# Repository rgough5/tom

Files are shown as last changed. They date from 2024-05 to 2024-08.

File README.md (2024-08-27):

# TOM Observes Mice (single pi)
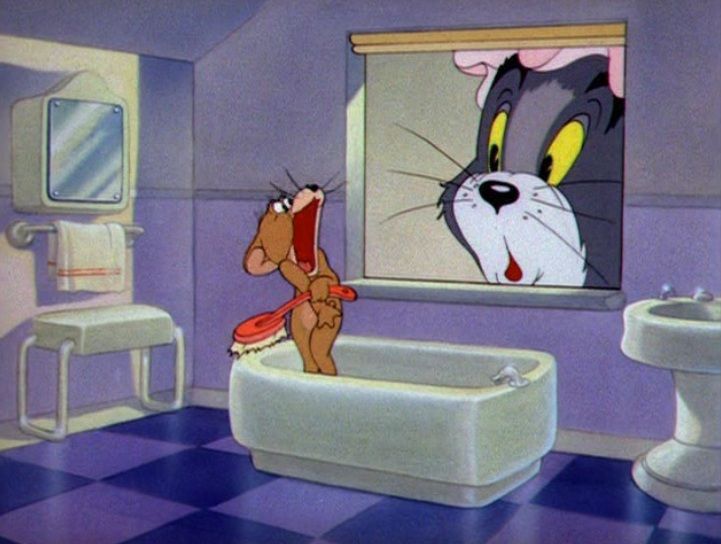
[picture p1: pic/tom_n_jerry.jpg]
this is fair use right?


While stable and functional, TOM is still a bit clunky so please report an issues. Note that it may be difficult to run further processes on the RasPi while recording and would only recommend live video analysis if you modify the AV data to be streamed as opposed to locally saved.

TOM Observes Mice (TOM) is a simple and relatively cheap tool for scientists interested in peeping on mice in their natural habit. Their home cage.
With a second raspberry pi, you can also record ultrasonic audio that will be syncronized with video.
Once setup, this tool is simple to use and written in Python so that other researchers can modify it as necessary.

## Required Hardware
- raspberry pi 5
- 5V/5A power adapter
- [solid state drive](https://www.amazon.com/SAMSUNG-Technology-Intelligent-Turbowrite-Sequential/dp/B08V7GT6F3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) and an [SSD hat](https://www.amazon.com/GeeekPi-N07-Peripheral-Raspberry-Support/dp/B0CWD266XR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)
    - note that gen4 SSDs are not compaitble with current SSD mounts. The highest you can go is gen3
    - with default settings you should be able to record for a minimum of a month before the SSD is full.
- raspberry pi camera [with IR filter removed](https://www.raspberrypi.com/documentation/accessories/camera.html#filter-removal)
- camera lens
    - tested with arducam 120 degree wide angle lens
- Dodotronic ultramic UM250K microphone
    - Requires separate USB A-to-mini-B cable

## Recommended Hardware
- Some sort of case. .dxf file include in the repository can be used to cut a frame out of 2.75mm acrylic, but this frame is flimsy and provides little protection. The pi(s) and camera are held in place using 12 m2.5 screws and nuts with the laser cut washers acting as spacers.
- Cooling. While heatsinks were sufficient in testing, I recommend active cooling with a fan.
- A router and potentially network switches to setup a LAN for communication between pis and a long term storage.

## Build
Instructions with pictures to come when more general casing is designed.

### Installation
1. Install Raspberry Pi OS (lite recommended) onto your SSD with custom settings. In the custom settings select username, a unique hostname, setup wifi, and **most importantly** enable SSH.
    - Be sure to enter a hostname unique to other devices on network.
2. Before progressing, the pi will need to be on and [connected to the internet](https://www.raspberrypi.com/documentation/computers/configuration.html#networking).
3. It's good practice on first boot to run `sudo apt-get update` and `sudo apt-get upgrade`
4. enter `curl -O https://raw.githubusercontent.com/rgough5/tom/main/install_tom.sh` to download the installer
5. Run the install file `bash install_tom.sh`.
6. *Optional:* Currently, files are transfered to another computer over ssh. You will need to setup passwordless connections if you want to use this.

### Usage
1. **If** you would like to run the raspi headless *(recommendeded)*.
    1. Connect the controlling computer to the same network as the pi.
    2. Connect to the raspi with `ssh -XC user@ip`.
2. **If** you would like to automatically setup
2. Run the python script with `python recAV.py`
    1. You will prompted to enter the file prefix, recording length, whether to record audio, and whether to transfer files after recordings

### Issues
- Adjusting settings is difficult and typically results in worse image.
- When recording with audio, video quality must be limitted to 10fps and 480p. Great for file size and good enough for most longitudinal use cases.

### In progress
- Working on GUI

Contact Rhys at rgough5@jhu.edu for any questions, requests, etc.

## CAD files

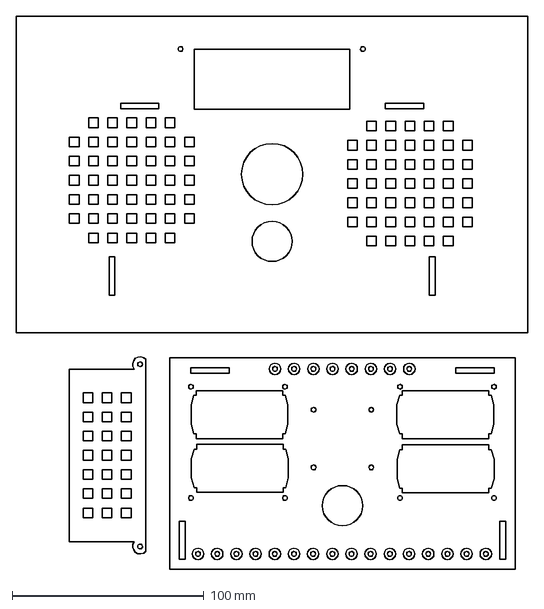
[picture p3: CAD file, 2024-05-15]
housing/cage_lid.DXF
266.7 x 288.3 mm

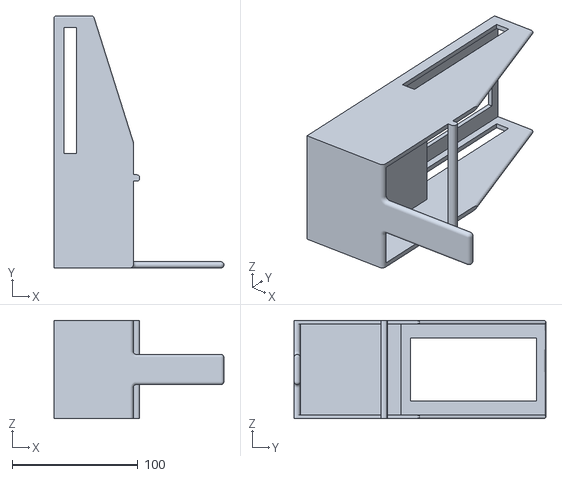
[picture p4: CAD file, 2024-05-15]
housing/bottleholder2.STL
135.0 x 200.0 x 78.0

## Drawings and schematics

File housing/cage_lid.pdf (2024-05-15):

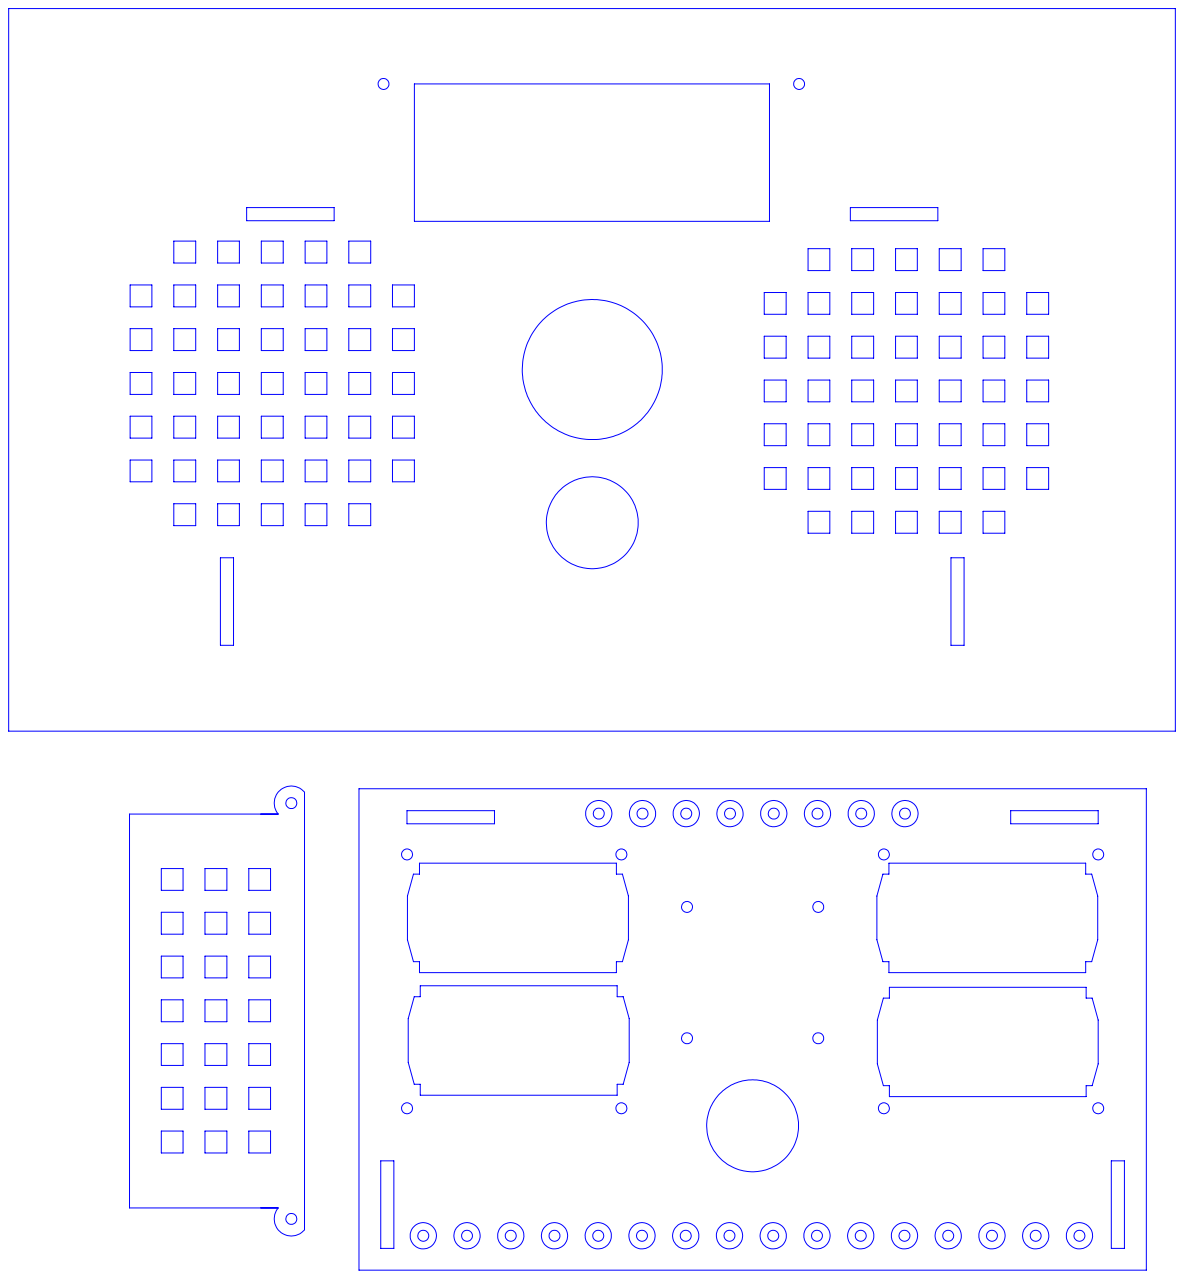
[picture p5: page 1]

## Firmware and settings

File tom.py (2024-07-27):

#!/opt/rec/bin/python
# Author: Rhys Gough of the Karigo Lab
# Usage: ./v_tom.py <recording name> <recording length>
# A preview window will open to ensure the camera is position fine.
# The preview window will close and the recording starts after indicating
# whether the user wants to record audio on a connected pi.

from picamera2 import Picamera2, Preview, controls
from picamera2.encoders import H264Encoder, MJPEGEncoder, Quality
from picamera2.outputs import FfmpegOutput, FileOutput
from libcamera import controls
import sounddevice as sd
import soundfile as sf
import queue
import sys
from datetime import datetime # what a dumb import
import time
import subprocess

# From the Picamera 2 Docs:
# Every camera frame may not take less than the first value
# nor longer than the second. FR = 1000000 / frame_duration. Common settings:
# 10 FPS = (100000, 100000), 30 FPS = (33333, 33333), 25 FPS (40000, 40000)

# how long to record before starting next track
# (note that wav files cap out at 2 GB or ~2 hours at 250000 Hz)

def recA(fname, dur, fs=250000, ch=1, mic_key = 'ltramic'):

    try:
        dev_i = sd.query_devices(device=mic_key)['index']
        #apparent bug on linux where the only available sampling rate is the mic's default

    except ValueError:
        print('unable to find Ultramic, trying default device')
        print(sd.query_devices())
        dev_i = 0
        fs = int(sd.query_devices(0)['default_samplerate'])
        ch = 1
    q = queue.Queue()
    def callback(indata, frames, time, status):
        #This is called (from a separate thread) for each audio block.
        if status:
            print(status, file=sys.stderr)
            q.put(indata.copy())

        q.put(indata.copy())
    t = time.time()
    try:
        with sf.SoundFile(fname+".flac", mode='w', samplerate=fs, channels=ch, subtype='PCM_S8') as f: #potentially should change w to x in final app to prevent overwritting
            with sd.InputStream(samplerate = fs, device = dev_i, channels = ch, callback = callback):
                print("recording audio, interrupt to stop")
                while time.time()-t < dur:
                    f.write(q.get())
    except KeyboardInterrupt:
        print("\ninterrupted")
    print("finished recording "+fname)
    # subprocess.Popen("scp {} {}".format(fname, storage)

def recAV(picam, fname, dur, enc, a='n'):
    out = FfmpegOutput(fname+'.mp4')
    picam.start_encoder(enc, out, quality=Quality.LOW)
    picam.start()
    print('recording ' + fname)
    if a == 'y':
        recA(fname, dur)
    else:
        time.sleep(dur)
    picam.stop()
    picam.stop_encoder()

def rTran(file, adrs):
    for attempt in range(5):
        try:
            subprocess.Popen("rsync {}.* {}".format(file, adrs), shell=True)
        except:
            print('transfer failed {}'.format(attempt))
            time.sleep(1)
        else:
            break

if __name__=='__main__':
    sz= (640, 480)
    frame_duration=(100000, 100000)
    exposure=1000
    sharpness=4
    seg=3600

    auto = 'a'
    transfer = 't'
    ### setup section ###
    # fname = sys.argv[1]
    # t = int(sys.argv[2])

    picam = Picamera2()
    cam_config = picam.create_video_configuration({'size': sz, 'format': 'YUV420'}, controls={'FrameDurationLimits': frame_duration, 'ExposureTime': exposure, 'Saturation': 0, 'NoiseReductionMode': controls.draft.NoiseReductionModeEnum.Off, 'Sharpness': sharpness})
    picam.configure(cam_config)
    encoder = H264Encoder()
    print('Adjust camera as desired. Recording will start after audio selection')
    print('Alternatively, cancel now with Ctrl+C')
    picam.start_preview(Preview.QT) #inefficient way to preview, but necessary to view over ssh
    picam.start()
    fname = input("File prefix: ")
    t = int(input("Time in seconds to record: "))

    while not(auto.lower() == 'y' or auto.lower() == 'n'):
        auto = input('Record with audio? (y/n) ')

    while not(transfer.lower() == 'y' or transfer.lower() == 'n'):
        transfer = input('Transfer files? (y/n) ')

    try:
        picam.stop_preview()
    except:
        pass
    picam.stop()

    ### recording section ###
    if transfer.lower() == 'y':
        transfer_address = input('Transfer address: ')

    i = 0
    while i < t//seg:
        i_fname = '{}_{}_{:%m%d%y-%H%M%S}'.format(fname, str(i), datetime.now())
        recAV(picam, i_fname, seg, encoder, a=auto.lower())
        if transfer == 'y':
            rTran(i_fname, transfer_address)
        i += 1

    ft = t%seg
    if ft != 0:
        i_fname = '{}_{}_{:%m%d%y-%H%M%S}'.format(fname, str(i), datetime.now())
        recAV(picam, i_fname, ft, encoder, a=auto.lower())
        if transfer == 'y':
            rTran(i_fname, transfer_address)

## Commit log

2024-05-07 fixed bugs in main .py files, updated readme
    [a_tom.py, v_tom.py]
2024-05-15 Added updated case
    [cage_lid.DXF]
2024-05-15 added bottle holder file
    [bottleholder2.STL]
2024-05-15 rearranged files
    [bottleholder2.STL, cage_lid.DXF]
2024-05-22 fixed stuff that I shouldn't have touched
    [v_tom.py]
